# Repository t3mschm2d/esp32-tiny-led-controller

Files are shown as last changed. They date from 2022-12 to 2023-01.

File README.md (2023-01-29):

# ESP32-Tiny-LED-Controller

## Overview

The main goal of this project is to develop an OpenHardware board for controlling digital LED strips. The control shall be done via [Homeassistant](https://www.home-assistant.io) and [esphome](https://esphome.io).The PCB is based around an [ESP32-U4WDH](https://www.espressif.com/sites/default/files/documentation/esp32_datasheet_en.pdf) microcontroller and includes the following features: 

- 2,4GHz antenna for WLAN / Bluetooth 
- 5 pin screw terminal for external power and the LED-strip 
- USB-C connector
- USB-to-UART converter
- JST PH-S4B for connecting external sensors 

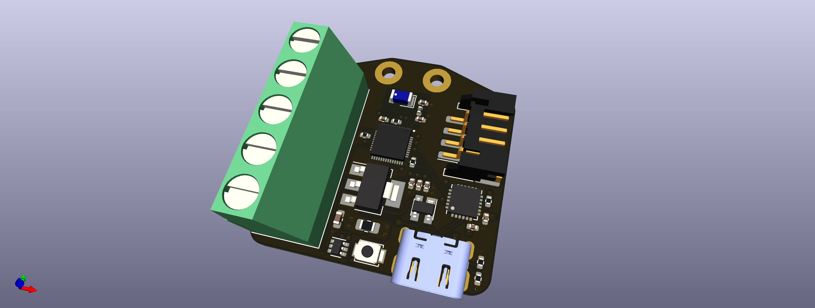
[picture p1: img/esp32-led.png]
board view


## ToDos

This PCB is a work in progress. The latest design is not tested and verified.

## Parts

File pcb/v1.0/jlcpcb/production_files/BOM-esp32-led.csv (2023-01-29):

Comment | Designator | Footprint | LCSC
5.11k | R6,R7 | R_0402_1005Metric | C103084
10p | C2 | C_0402_1005Metric | C106199
100k | R1,R2 | R_0402_1005Metric | C106234
1k | R3 | R_0402_1005Metric | C106235
100n | C3,C9 | C_0402_1005Metric | C131394
499R | R4 | R_0402_1005Metric | C137970
0R | R5 | R_0805_2012Metric_Pad1.20x1.40mm_HandSolder | C169855
SW_Push | SW1 | SW_SPST_B3U-1000P | C231329
1n | L1 | L_0402_1005Metric | C237608
JST-PH-4 | J3 | JST_PH_S4B-PH-SM4-TB_1x04-1MP_P2.00mm_Horizontal | C265102
10n | C5 | C_0402_1005Metric | C272878
YAGEO_ANT3216LL00R2400A | A1 | YAGEO_ANT3216LL00R2400A | C293767
ESP32-U4WDH | IC1 | QFN35P500X500X90-49N-D | C3013932
SP0503BAHT | D1 | SOT-143 | C3040626
8p | C1 | C_0402_1005Metric | C342939
MUN5211DW1 | Q1 | SOT-363_SC-70-6 | C463894
AMS1117-3.3 | U2 | SOT-223-3_TabPin2 | C6186
10u | C7 | C_0402_1005Metric | C76991
4.7u | C4,C8 | C_0402_1005Metric | C82453
10u | C6 | C_0603_1608Metric | C85713
CP2102N-Axx-xQFN24 | U1 | QFN-24-1EP_4x4mm_P0.5mm_EP2.6x2.6mm | C969151

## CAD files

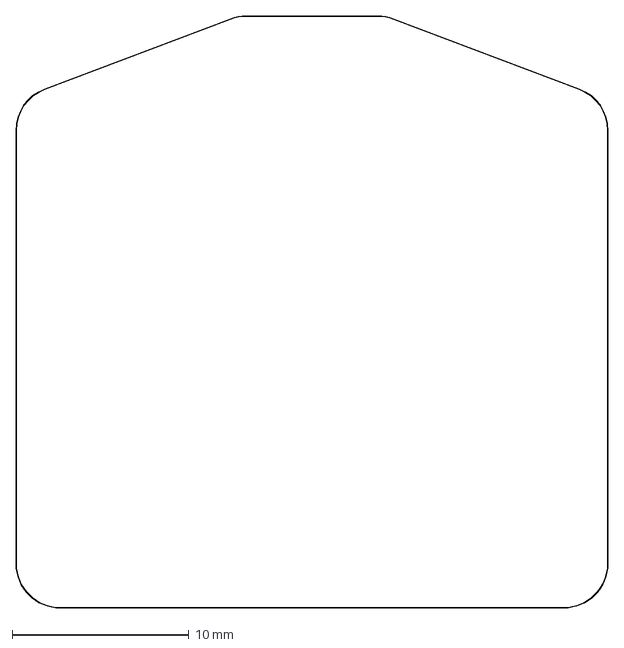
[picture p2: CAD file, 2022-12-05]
pcb/v1.0/board-outline/Board-Outline.dxf
33.5 x 33.5 mm

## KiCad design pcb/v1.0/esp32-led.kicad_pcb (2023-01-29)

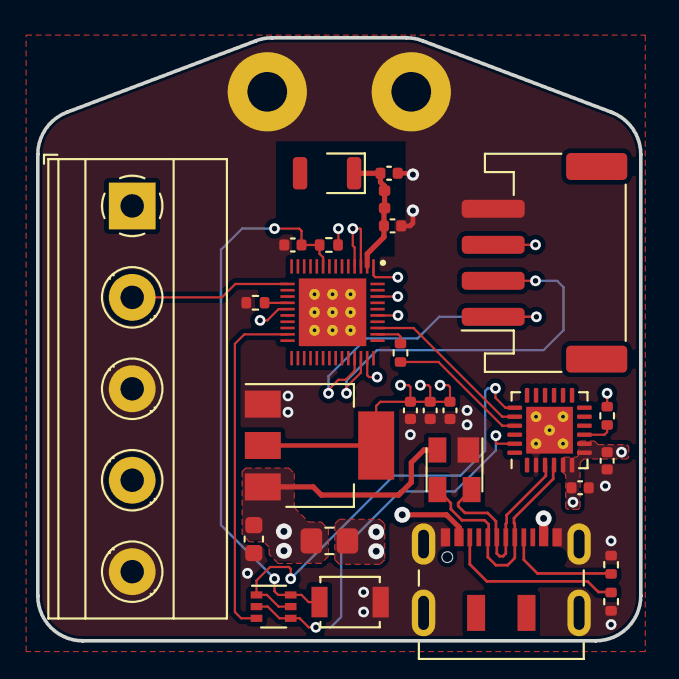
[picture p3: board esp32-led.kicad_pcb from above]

Board: 4 copper layers, 33.5 x 33.5 mm, 29 parts (0 on the bottom side), 21 nets.

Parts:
A1: YAGEO_ANT3216LL00R2400A
C1: 8p; C_0402_1005Metric
C2: 10p; C_0402_1005Metric
C3, C9: 100n; C_0402_1005Metric
C4, C8: 4.7u; C_0402_1005Metric
C5: 10n; C_0402_1005Metric
C6: 10u; C_0603_1608Metric
C7: 10u; C_0402_1005Metric
D1: SP0503BAHT; SOT-143
H1, H2: MountingHole_Pad; MountingHole_2.2mm_M2_Pad
IC1: ESP32-U4WDH; QFN35P500X500X90-49N-D
J1: USB_C_Receptacle_USB2.0; USB_C_Receptacle_JAE_DX07S016JA1R1500
J2: Screw_Terminal_01x05; TerminalBlock_Phoenix_MKDS-1,5-5-5.08_1x05_P5.08mm_Horizont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
J3: JST-PH-4; JST_PH_S4B-PH-SM4-TB_1x04-1MP_P2.00mm_Horizontal
L1: 1n; L_0402_1005Metric
Q1: MUN5211DW1; SOT-363_SC-70-6
R1, R2: 100k; R_0402_1005Metric
R3: 1k; R_0402_1005Metric
R4: 499R; R_0402_1005Metric
R5: 0R; R_0805_2012Metric_Pad1.20x1.40mm_HandSolder
R6: 5.11k; R_0402_1005Metric
R7: 5.11K; R_0402_1005Metric
SW1: SW_Push; SW_SPST_B3U-1000P
U1: CP2102N-Axx-xQFN24; QFN-24-1EP_4x4mm_P0.5mm_EP2.6x2.6mm
U2: AMS1117-3.3; SOT-223-3_TabPin2

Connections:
+3V3: C4.1, C5.1, C7.1, C8.1, C9.1, IC1.1 (VDDA_1), IC1.3 (VDD3P3_1), IC1.4 (VDD3P3_2), IC1.19 (VDD3P3_RTC), IC1.37 (VDD3P3_CPU), IC1.43 (VDDA_2), IC1.46 (VDDA_3), J3.3, R1.1, R3.1, U1.5 (VIO), U1.6 (VDD), U1.7 (VREGIN), U1.8 (VBUS), U2.2 (VO)
+5V: C6.1, D1.2 (K), J2.1, J2.4, R5.2, U2.3 (VI)
/5V to 3.3V Power/CC1: J1.A5 (CC1), R7.1
/5V to 3.3V Power/CC2: J1.B5 (CC2), R6.1
/5V to 3.3V Power/VBUS: J1.A4 (VBUS), J1.A9 (VBUS), J1.B4 (VBUS), J1.B9 (VBUS), R5.1
/ESP32-U4WDH/ANTENNA: A1.1 (Feed-In), C1.1, C2.1, IC1.2 (LNA_IN), L1.1, L1.2
/ESP32-U4WDH/MTDI: IC1.18 (MTDI), R2.1
/USB to UART /DTR: Q1.2 (B2), Q1.4 (E1), U1.23 (~DTR)
/USB to UART /RST: R3.2, U1.9 (~RST)
/USB to UART /RTS: Q1.1 (E2), Q1.5 (B1), U1.19 (~RTS)
/USB to UART /TXD: R4.1, U1.21 (TXD)
D+: D1.4 (K), J1.A6 (D+), J1.B6 (D+), U1.3 (D+)
D-: D1.3 (K), J1.A7 (D-), J1.B7 (D-), U1.4 (D-)
EN: C3.1, IC1.9 (CHIP_PU), Q1.6 (C2), R1.2, SW1.1
GND: C1.2, C2.2, C3.2, C4.2, C5.2, C6.2, C7.2, C8.2, C9.2, D1.1 (A), H1.1, H2.1, IC1.49 (EP), J1.A1 (GND), J1.A12 (GND), J1.B1 (GND), J1.B12 (GND), J1.S1 (SHIELD), J2.3, J2.5, J3.4, R2.2, R6.2, R7.2, SW1.2, U1.2 (GND), U1.25 (GND), U2.1 (GND)
GPIO0: IC1.23 (GPIO0), Q1.3 (C1)
GPIO26: IC1.15 (GPIO26), J2.2
SCL: IC1.35 (GPIO18), J3.1
SDA: IC1.36 (GPIO23), J3.2
U0RXD: IC1.40 (U0RXD), R4.2
U0TXD: IC1.41 (U0TXD), U1.20 (RXD)

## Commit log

2022-11-18 ADD initial schematic and first layout plans
    [5V-to-3V3-power.kicad_sch, esp32-led.kicad_pcb, esp32-led.kicad_sch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]
2022-11-22 ADD placement and rounting for ESP32-LED Driver
    [5V-to-3V3-power.kicad_sch, esp32-led.kicad_pcb]
2022-11-23 ADD subfolder for pcb
    [5V-to-3V3-power.kicad_sch, esp32-led.kicad_pcb, esp32-led.kicad_sch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]
2022-11-26 Add board view to README
2022-12-01 ADD 3D Models for all footprints, export new PCB Image and remove D1 for R8 with 0R (Jumper R)
    [5V-to-3V3-power.kicad_sch, esp32-led.kicad_pcb, esp32-led.kicad_sch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]
2022-12-02 ADD new picture, and propper GND plane on top layer
    [5V-to-3V3-power.kicad_sch, esp32-led.kicad_pcb, esp32-led.kicad_sch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]
2022-12-02 UPDATE thermal relief pads for ESP, USB-UART
    [esp32-led.kicad_pcb]
2022-12-05 REF PCB Layout, Switch to new USB-C Receptable
    [5V-to-3V3-power.kicad_sch, Board-Outline.dxf, esp32-led.kicad_pcb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]
2022-12-05 REF TVS-Diode Layout
    [esp32-led.kicad_pcb]
2023-01-29 ADD new READ.me
    [5V-to-3V3-power.kicad_sch, BOM-esp32-led.csv, Board-Outline.dxf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]
